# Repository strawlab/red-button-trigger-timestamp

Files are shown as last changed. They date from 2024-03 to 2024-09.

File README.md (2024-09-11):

# red-button-trigger-timestamp 🔘 for Raspberry Pi Pico

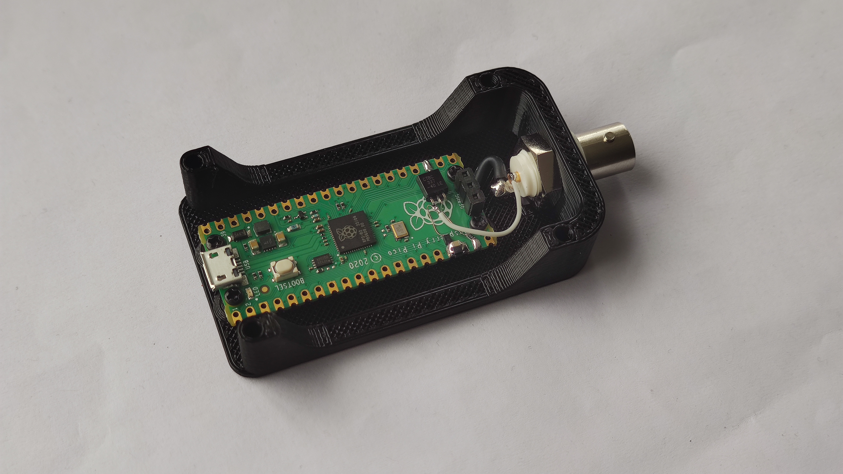
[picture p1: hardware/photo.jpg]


This device allows using a Raspberry Pi Pico board to capture accurate timing
information at the time an external trigger fired. We use it with
[FLO](https://github.com/strawlab/flo) to log when exactly our high speed
cameras were triggered.

Directories:

- `firmware` - source code for the firmware to be flashed on the Raspberry Pi Pico
- `red-button-trigger-timestamp` - source code for the command-line program
  running on a host PC which talks to the Pico and writes a `.csv` file with the
  trigger timestamps
- `red-button-trigger-timestamp-comms` - source code defining messages types passed between the Pico and the host PC
- `hardware` - schematic and 3d-printed enclosure

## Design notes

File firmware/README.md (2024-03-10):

# red-button-trigger-timestamp-firmware 🔘 for Raspberry Pi Pico

## Building

### Install prerequisites

```
rustup target install thumbv6m-none-eabi
cargo install flip-link --locked
cargo install elf2uf2-rs --locked
```

### Build firmware

```
cargo build --release
elf2uf2-rs target/thumbv6m-none-eabi/release/red-button-trigger-timestamp-firmware
```

You should now have the file `red-button-trigger-timestamp-firmware.uf2` in the
`target/thumbv6m-none-eabi/release` directory. This is the firmware file which
you should flash to your pico.

### Install firmware

Hold down the BOOTSEL (short for boot select) button on the Pico and plug it
into your machine. It should appear as a flash drive. Copy the
`red-button-trigger-timestamp-firmware.uf2` file to this "flash drive".

## Debugging with Knurling (`probe-rs`)

We use the Knurling project to facilitate debugging. `probe-rs` can be used to
debug the device from a host computer and view log messages send using the
`defmt` infrastructure. Install `probe-rs` with `cargo install probe-rs --features cli`.

To see `defmt` messages, compile with the `DEFMT_LOG` environment variable
set appropriately. (By default, `defmt` will show only error level messages.)

Powershell (Windows)
```
$Env:DEFMT_LOG="trace"
```

Bash (Linux/macOS)
```
export DEFMT_LOG=trace
```

### Probe

Run with:

```
cargo run --release
```

# License

Portions of this project are derived from the cortex-m-quickstart project, which
is licensed under either of

- Apache License, Version 2.0 ([LICENSE-APACHE](LICENSE-APACHE) or
  http://www.apache.org/licenses/LICENSE-2.0)

- MIT license ([LICENSE-MIT](LICENSE-MIT) or http://opensource.org/licenses/MIT)

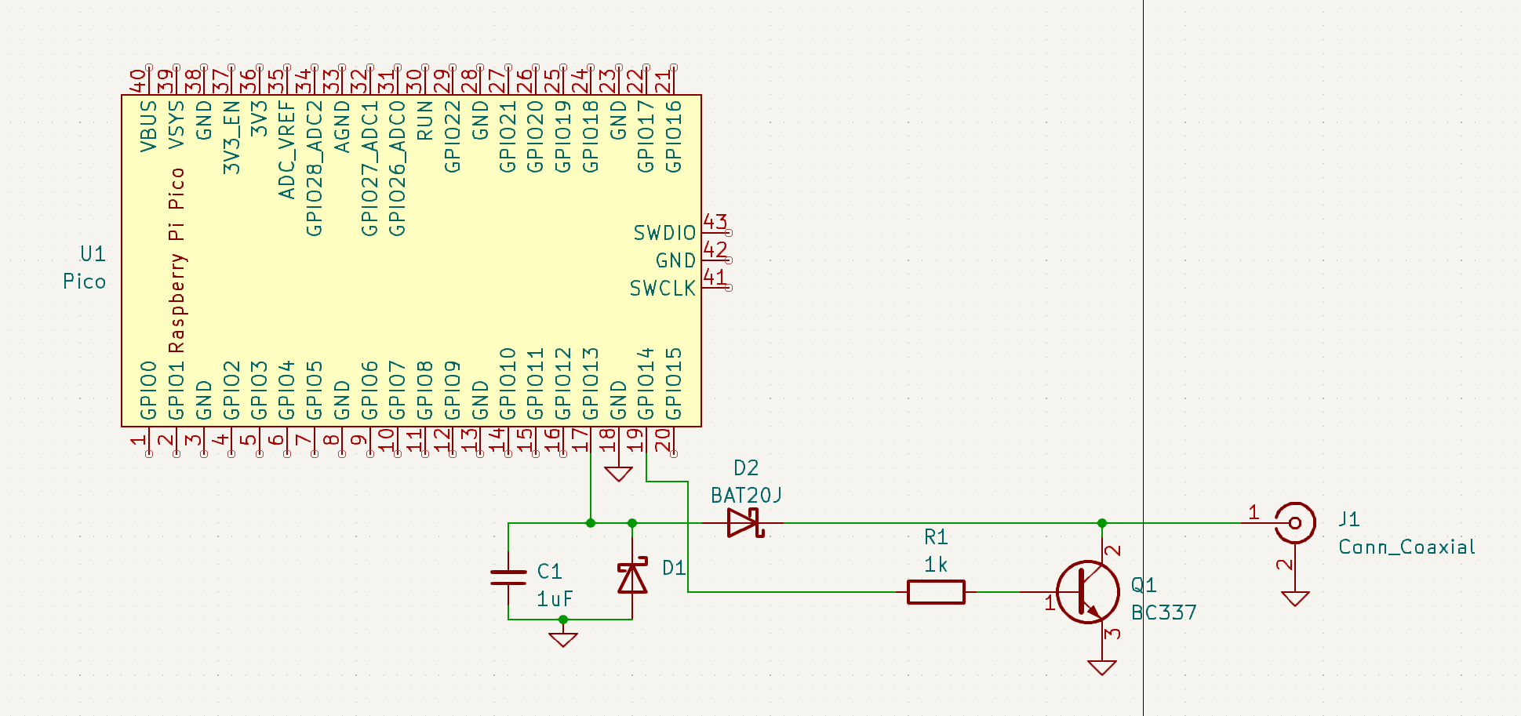
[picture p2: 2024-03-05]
hardware/schematic.png

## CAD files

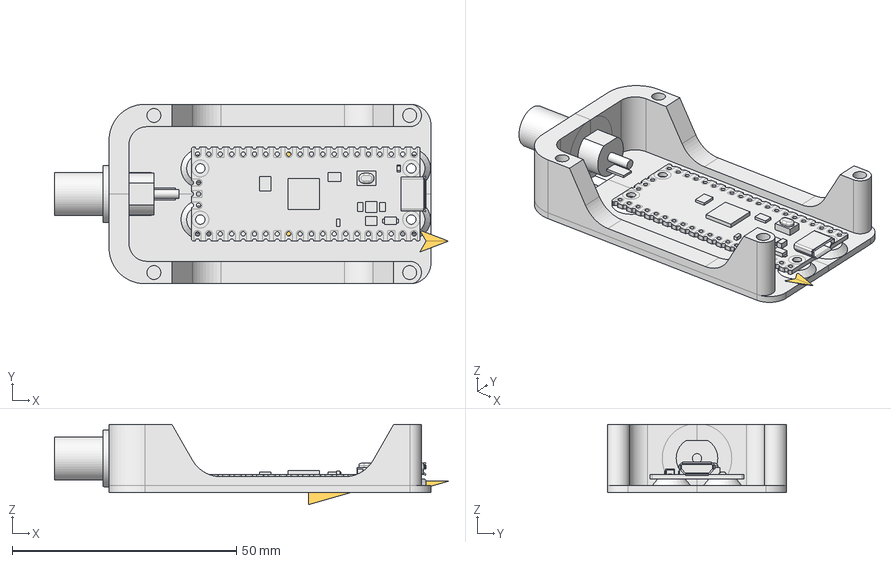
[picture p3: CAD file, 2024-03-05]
hardware/enclosure/trigger-sniffer-box-v01.FCStd
87.8 x 40.0 x 17.9 mm
BNCConnector
origin
Placment001
Moved Pico-R3
box base

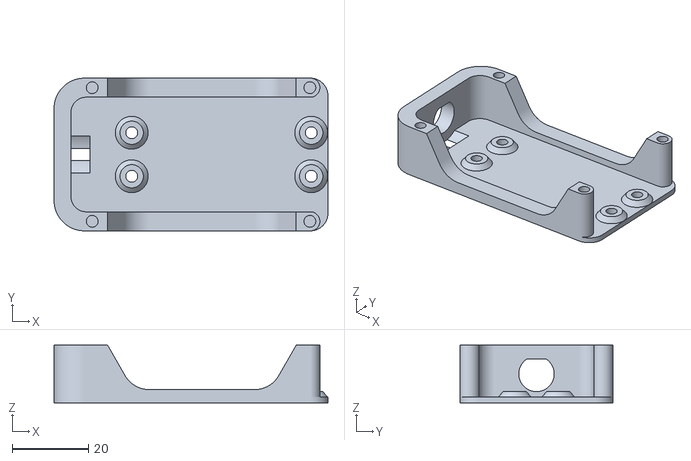
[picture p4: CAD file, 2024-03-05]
hardware/enclosure/trigger-sniffer-box-v01 box base.stl
71.7 x 40.0 x 15.1

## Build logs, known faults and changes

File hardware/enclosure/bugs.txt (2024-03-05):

v01:
* base plate too thin
* base to board gap too narrow, thick gnd wire doesn't fit
* holes for pico too shallow, inserts don't fit
* it is very tricky to screw on the connector and then solder it, ground is inaccessible
* the hole for bnc connector is too narrow, probably thanks to a droopy bridge. Requires a bit of grinding.

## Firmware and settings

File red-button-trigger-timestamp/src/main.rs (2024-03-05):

use clap::Parser;
use color_eyre::eyre::{self as anyhow, WrapErr};
use futures::{SinkExt, StreamExt};
use json_lines::codec::JsonLinesCodec;
use red_button_trigger_timestamp_comms::{FromDevice, ToDevice, VersionResponse};
use serde::Serialize;
use tokio_serial::SerialPortBuilderExt;
use tracing_subscriber::{fmt, layer::SubscriberExt};

mod clock_model;

#[derive(Serialize)]
struct TriggerRow {
    timestamp_local: chrono::DateTime<chrono::Local>,
    epoch_nanos_utc: i64,
}

#[derive(Parser)]
struct Cli {
    /// Serial device to open
    device_path: Option<String>,

    /// Output directory
    #[arg(short, long, default_value = "~/TRIGGER_DATA")]
    output_dir: String,
}

fn to_device_name(spi: &tokio_serial::SerialPortInfo) -> String {
    let name = spi.port_name.clone();
    // This is necessary on linux:
    name.replace("/sys/class/tty/", "/dev/")
}

#[tokio::main]
async fn main() -> anyhow::Result<()> {
    if std::env::var_os("RUST_LOG").is_none() {
        std::env::set_var("RUST_LOG", "info");
    }
    let collector = tracing_subscriber::registry()
        .with(fmt::layer())
        .with(tracing_subscriber::filter::EnvFilter::from_default_env());
    tracing::subscriber::set_global_default(collector)?;

    let opt = Cli::parse();
    let device_path = match opt.device_path {
        None => {
            let available_ports: Vec<_> = tokio_serial::available_ports()?
                .iter()
                .map(to_device_name)
                .filter(|x| x != "/dev/ttyS0")
                .collect();
            println!("No device path was given. Available options:");
            for p in available_ports.iter() {
                println!("{p}");
            }
            return Ok(());
        }
        Some(p) => p,
    };
    let baud_rate = 115_200;
    tracing::info!("Opening device at path {}", device_path);

    #[allow(unused_mut)]
    let mut serial_device = tokio_serial::new(&device_path, baud_rate)
        .open_native_async()
        .with_context(|| format!("opening device {device_path}"))?;
    tracing::info!("Device opened");

    #[cfg(unix)]
    serial_device
        .set_exclusive(false)
        .expect("Unable to set serial port exclusive to false");

    let local = chrono::Local::now();
    let output_filename_template = "triggers_%Y%m%d_%H%M%S.csv".to_string();
    let filename = local.format(&output_filename_template).to_string();

    let output_dir = std::path::PathBuf::from(shellexpand::full(&opt.output_dir)?.to_string());
    std::fs::create_dir_all(&output_dir)
        .with_context(|| format!("ensuring existence of directory {}", output_dir.display()))?;

    let full_path = output_dir.join(filename);
    let fd = std::fs::File::create(&full_path)
        .with_context(|| format!("creating file {}", full_path.display()))?;
    tracing::info!("Saving data to {}", full_path.display());
    let mut csv_wtr = csv::Writer::from_writer(fd);

    let framed = tokio_util::codec::Framed::new(
        serial_device,
        JsonLinesCodec::<FromDevice, ToDevice>::default(),
    );

    let (mut device_tx, mut device_rx) = framed.split();

    device_tx.send(ToDevice::VersionRequest).await?;
    let version_request_sent = std::time::Instant::now();
    let mut did_receive_version_response = false;

    let mut last_ping = chrono::Utc::now();
    let mut last_pong = chrono::Utc::now();

    let mut interval = tokio::time::interval(std::time::Duration::from_secs(1));
    let mut clock_model = clock_model::ClockModel::default();
    loop {
        tokio::select! {
            Some(from_device) = device_rx.next() => {
                let recv_time = chrono::Utc::now();
                match from_device? {
                    FromDevice::Pong(device_timestamp) => {
                        last_pong = chrono::Utc::now();
                        clock_model.update(last_ping,recv_time,device_timestamp);
                        tracing::debug!("pong utc: {:?}", clock_model.compute_utc(device_timestamp));
                    }
                    FromDevice::Trigger(device_timestamp) => {
                        if let Some(trigger_utc) = clock_model.compute_utc(device_timestamp) {
                            let timestamp_local: chrono::DateTime<chrono::Local> =
                            trigger_utc.with_timezone(&chrono::Local);
                            tracing::info!("trigger: {}", timestamp_local);
                            let delta_epoch = trigger_utc - chrono::DateTime::UNIX_EPOCH;
                            let epoch_nanos_utc = delta_epoch.num_nanoseconds().unwrap();
                            let trig_row = TriggerRow {
                                timestamp_local,
                                epoch_nanos_utc,
                            };
                            csv_wtr.serialize(trig_row)?;
                            csv_wtr.flush()?;
                        } else {
                            tracing::error!("Could not compute trigger time.");
                        }
                    }
                    FromDevice::VersionResponse(info) => {
                        let my_info = VersionResponse::default();
                        if info != my_info {
                            anyhow::bail!("firmware has version {:?}, but program has version {:?}", info,my_info);
                        }
                        tracing::info!("Connected to firmware \"{}\" v{}", String::from_utf8_lossy(&info.name), info.version);
                        did_receive_version_response = true;
                    }
                }
            }
            _ = interval.tick() => {
                last_ping = chrono::Utc::now();
                device_tx.send(ToDevice::Ping).await?;
                let delta = last_ping - last_pong;
                if delta > chrono::TimeDelta::seconds(5) {
                    tracing::error!("No communication with device in {} seconds.", delta.num_milliseconds()as f64/1000.0);
                }
            }
        }

        if !did_receive_version_response
            && version_request_sent.elapsed() > std::time::Duration::from_secs(5)
        {
            anyhow::bail!("No version response received.");
        }
    }
}

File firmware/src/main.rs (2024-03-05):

#![no_std]
#![no_main]

use defmt_rtt as _;
use panic_probe as _;
use rtic::Mutex;

use red_button_trigger_timestamp_comms::{FromDevice, ToDevice};

use json_lines::accumulator::{FeedResult, NewlinesAccumulator};

#[rtic::app(device = rp_pico::hal::pac, peripherals = true, dispatchers = [I2C0_IRQ])]
mod app {
    use super::*;
    use rp_pico::XOSC_CRYSTAL_FREQ;

    use heapless::spsc::{Consumer, Producer, Queue};
    use usb_device::{class_prelude::*, prelude::*};
    use usbd_serial::SerialPort;

    use embedded_hal::digital::v2::{InputPin, OutputPin};
    use rp2040_hal::{
        self as hal, clocks::init_clocks_and_plls, usb::UsbBus, watchdog::Watchdog, Sio,
    };
    use rp2040_monotonic::Rp2040Monotonic;

    const MAX_FRAME_SZ: usize = 256;
    const NUM_FRAMES: usize = 8;
    type UsbFrame = heapless::Vec<u8, MAX_FRAME_SZ>;

    #[shared]
    struct Shared {
        green_led: hal::gpio::Pin<
            hal::gpio::bank0::Gpio25,
            hal::gpio::FunctionSioOutput,
            hal::gpio::PullNone,
        >,
        usb_serial: SerialPort<'static, UsbBus>,
    }

    #[monotonic(binds = TIMER_IRQ_0, default = true)]
    type Monotonic = Rp2040Monotonic;

    #[local]
    struct Local {
        trigger_pin: hal::gpio::Pin<
            hal::gpio::bank0::Gpio13,
            hal::gpio::FunctionSioInput,
            hal::gpio::PullUp,
        >,
        usb_dev: UsbDevice<'static, UsbBus>,
        rx_prod: Producer<'static, UsbFrame, NUM_FRAMES>,
        rx_cons: Consumer<'static, UsbFrame, NUM_FRAMES>,
    }

    #[init(local = [usb_bus: Option<UsbBusAllocator<UsbBus>> = None])]
    fn init(c: init::Context) -> (Shared, Local, init::Monotonics) {
        defmt::info!("Hello from {}.", env!["CARGO_PKG_NAME"]);
        let mut resets = c.device.RESETS;
        let mut watchdog = Watchdog::new(c.device.WATCHDOG);
        let clocks = init_clocks_and_plls(
            XOSC_CRYSTAL_FREQ,
            c.device.XOSC,
            c.device.CLOCKS,
            c.device.PLL_SYS,
            c.device.PLL_USB,
            &mut resets,
            &mut watchdog,
        )
        .ok()
        .unwrap();

        let usb_bus = c.local.usb_bus;
        usb_bus.replace(UsbBusAllocator::new(UsbBus::new(
            c.device.USBCTRL_REGS,
            c.device.USBCTRL_DPRAM,
            clocks.usb_clock,
            true,
            &mut resets,
        )));
        let usb_serial = SerialPort::new(usb_bus.as_ref().unwrap());

        let usb_dev = UsbDeviceBuilder::new(usb_bus.as_ref().unwrap(), UsbVidPid(0x16c0, 0x27dd))
            .manufacturer("Straw Lab")
            .product("Red Button Trigger Timestamp Logger")
            .serial_number("TEST")
            .device_class(2) // USB_CLASS_CDC
            .build();

        let sio = Sio::new(c.device.SIO);
        let pins = rp_pico::Pins::new(
            c.device.IO_BANK0,
            c.device.PADS_BANK0,
            sio.gpio_bank0,
            &mut resets,
        );

        let mut green_led = pins.led.reconfigure();
        green_led.set_low().unwrap();

        let trigger_pin = pins.gpio13.reconfigure();

        let rx_queue: &'static mut Queue<UsbFrame, NUM_FRAMES> = {
            static mut Q: Queue<UsbFrame, NUM_FRAMES> = Queue::new();
            unsafe { &mut Q }
        };
        let (rx_prod, rx_cons) = rx_queue.split();

        let mono = Monotonic::new(c.device.TIMER);

        (
            Shared {
                green_led,
                usb_serial,
            },
            Local {
                trigger_pin,
                usb_dev,
                rx_prod,
                rx_cons,
            },
            init::Monotonics(mono),
        )
    }

    fn send_response(
        response: &FromDevice,
        ctx: &mut idle::Context,
        &mut mut out_buf: &mut [u8; 256],
    ) {
        let encoded = json_lines::to_slice_newline(&response, &mut out_buf[..]).unwrap();

        ctx.shared.usb_serial.lock(|usb_serial| {
            match usb_serial.write(encoded) {
                // this can panic with WouldBlock
                Ok(_nbytes) => {
                    // Should we check if nbytes == encoded.len()?
                }
                Err(UsbError::WouldBlock) => {
                    defmt::error!("failed to send message: WouldBlock");
                }
                Err(e) => {
                    panic!("Writing message to USB: {e:?}");
                }
            }
        });
        defmt::trace!("sent {} bytes", encoded.len());
    }

    #[idle(shared = [usb_serial, green_led], local = [trigger_pin, rx_cons])]
    fn idle(mut ctx: idle::Context) -> ! {
        let mut decoder = NewlinesAccumulator::<512>::new();
        let mut out_buf = [0u8; 256];

        let mut prev_state = ctx.local.trigger_pin.is_high().unwrap();
        loop {
            let this_state = ctx.local.trigger_pin.is_high().unwrap();
            if this_state != prev_state {
                if !this_state {
                    let now = monotonics::Monotonic::now().ticks();
                    let response = FromDevice::Trigger(now);
                    send_response(&response, &mut ctx, &mut out_buf);
                    defmt::info!("Trigger: {}", now);
                }
                prev_state = this_state;
            }

            let frame = match ctx.local.rx_cons.dequeue() {
                Some(frame) => frame,
                None => continue,
            };
            let src = &frame.as_slice();

            let ret = match decoder.feed::<ToDevice>(src) {
                FeedResult::Consumed => None,
                FeedResult::OverFull(_remaining) => {
                    defmt::error!("frame overflow");
                    None
                }
                FeedResult::DeserError(_remaining) => {
                    defmt::error!("deserialization");
                    None
                }
                FeedResult::Success { data, remaining: _ } => Some(data),
            };

            if let Some(request) = ret {
                let response;
                defmt::info!("Request: {:?}", request);
                match request {
                    ToDevice::Ping => {
                        let now = monotonics::Monotonic::now().ticks();
                        response = FromDevice::Pong(now);
                        defmt::debug!("device state set");
                    }
                    ToDevice::VersionRequest => {
                        response = FromDevice::VersionResponse(Default::default());
                    }
                }
                defmt::info!("Response: {:?}", response);
                send_response(&response, &mut ctx, &mut out_buf);
            }
        }
    }
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

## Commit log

2024-03-05 add hardware description and a photo
    [schematic.kicad_sch, trigger-sniffer-box-v01 box base.stl, trigger-sniffer-box-v01.FCStd]
2024-03-10 use 'probe-rs' to flash firmware
